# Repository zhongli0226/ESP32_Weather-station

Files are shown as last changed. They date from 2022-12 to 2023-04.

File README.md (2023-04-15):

# ESP32气象站

## 毕设版本V1.0.0

#### 介绍
开源一下我的毕业设计 

基于esp32设计的桌面时钟气象站

#### 架构说明

1. 主程序采用esp32-idf代码 版本为V4.3 芯片为esp32-pico。
2. pc模拟与主工程 LVGL采用V7.9版本 。
3. 硬件由使用AD画的，结构设计采用SOLIDWORKS组装。

#### 使用说明

1.  主工程在spi地方，本人修改了spi源码的一个变量，如直接编译提到代码，运行会出现spi报错，可根据需要进行修改一下。
2.  目前获取天气的网站采用心知天气，用的是本人自己的密钥，可根据需要更换为自己的。
3.  lvgl PC模拟器采用visual studio 2022 需要安装2019（v142）平台工具集，否则无法编译。

#### 未来计划

* [x] 取消SD卡配网方式，采用smartcofig和强制门户认证的方式，综合配网
* [ ] 硬件电路上增加锂电池电源管理部分
* [x] lvgl进一步学习，优化动画效果

## 改进版V2.0.0

#### 架构说明

1. 主程序采用esp32-idf代码 版本为V4.4 芯片为esp32-pico。
2. pc模拟与主工程 LVGL采用V7.10版本 。
3. 硬件延续采用V1.0.0版本，可兼容使用。

#### 改进说明

1. 配网方式采用smartcofig ，且带有存储WiFi信息功能，重新开机自动连接。
2. 优化主界面布局，UI布局优化
3. 取消SD卡输入WiFi信息和地址信息，利用IP定位确定地址。

#### 未来计划

* [ ] 硬件和结构的优化，整体布局优化
* [ ] 触摸按键功能考虑是否加上。

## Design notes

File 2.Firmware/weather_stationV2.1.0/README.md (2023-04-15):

# 桌面气象站升级

#### 介绍
项目来源于稚辉君所做的小电视，后作为我本科毕业设计，现工作后想要继续改进功能所创立。

#### 软件架构
软件架构说明 ESP32-IDF v4.4版本
                         LVGL v7.8.0版本

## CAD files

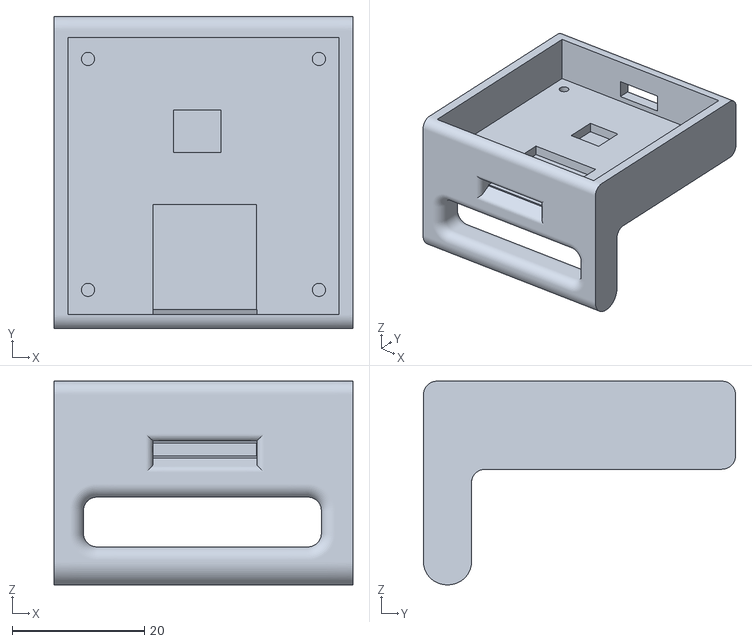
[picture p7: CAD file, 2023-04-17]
3.3D Model/V2.0.0/底座.stl
45.1 x 47.1 x 30.8

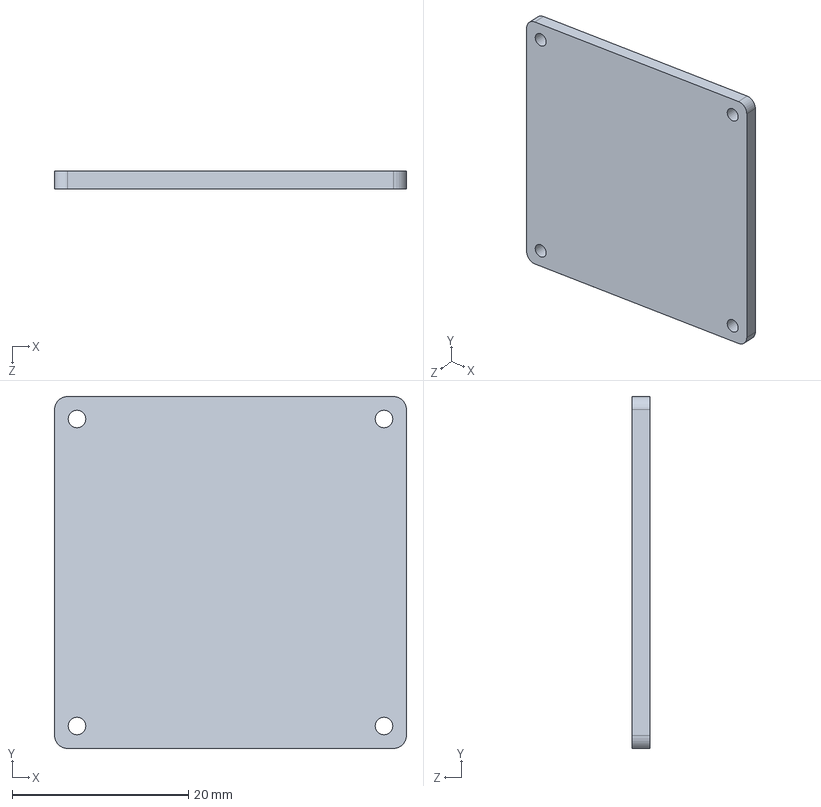
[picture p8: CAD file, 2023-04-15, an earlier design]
3.3D Model/V1.0.0/底板.SLDPRT
40.0 x 40.0 x 2.00 mm

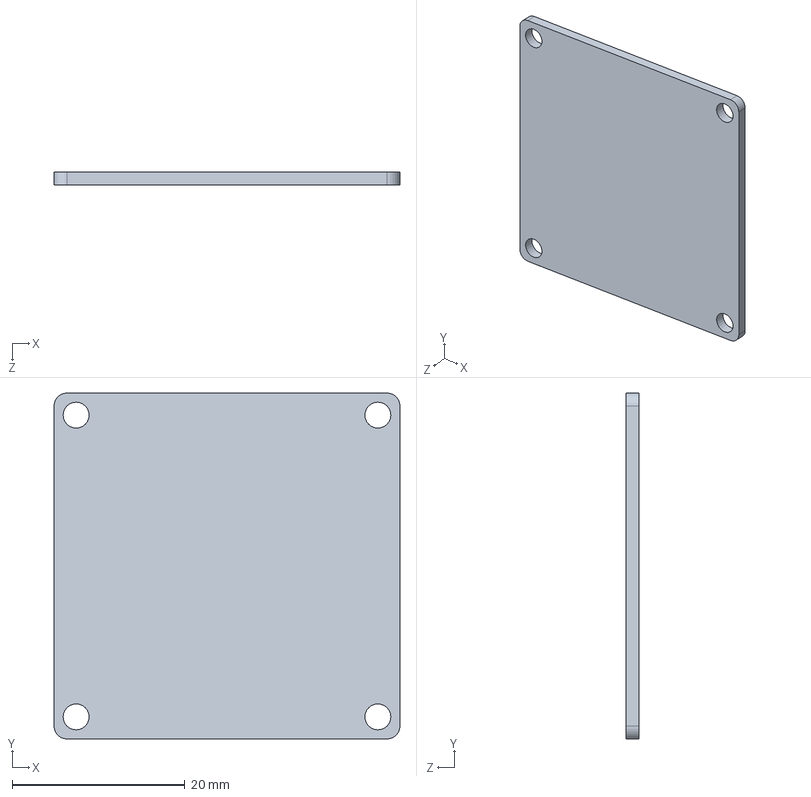
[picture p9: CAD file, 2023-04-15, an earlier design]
3.3D Model/V1.0.0/底板切割.SLDPRT
40.0 x 40.0 x 1.50 mm

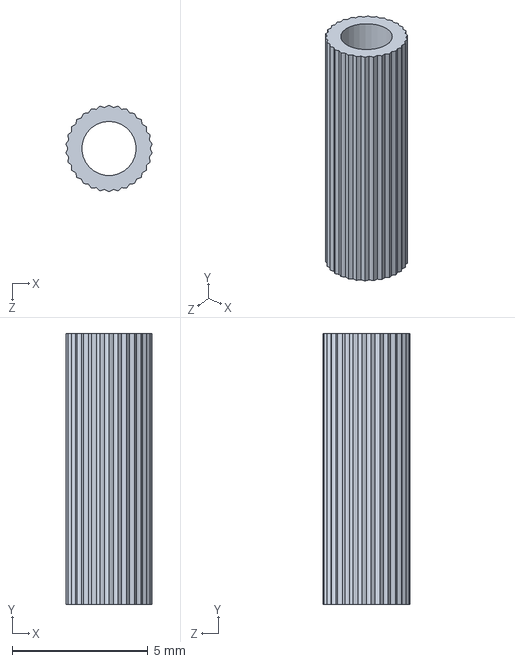
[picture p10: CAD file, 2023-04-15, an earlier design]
3.3D Model/V1.0.0/m2铜柱.SLDPRT
3.18 x 10.0 x 3.20 mm

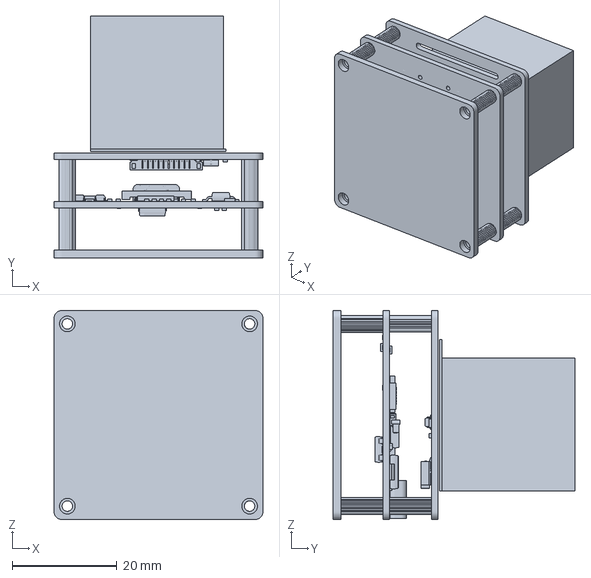
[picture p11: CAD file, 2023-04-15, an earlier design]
3.3D Model/V1.0.0/3d概念图.3MF
40.0 x 46.3 x 40.0 mm

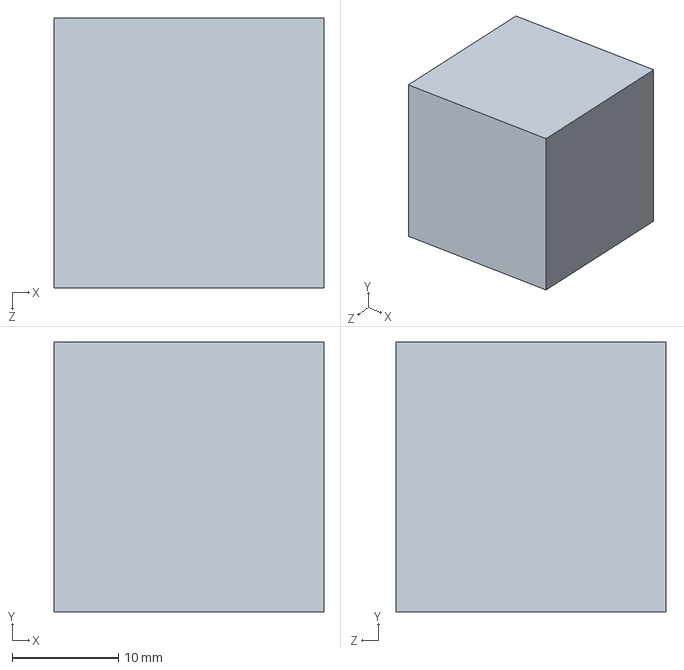
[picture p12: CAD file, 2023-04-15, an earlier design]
3.3D Model/V1.0.0/分光棱镜.SLDPRT
25.4 x 25.4 x 25.4 mm

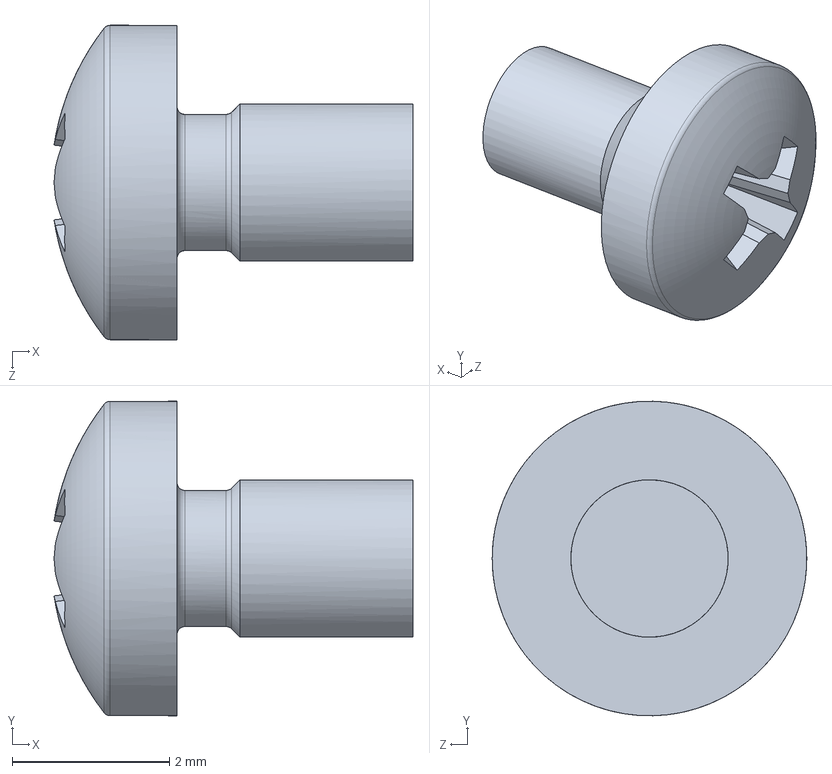
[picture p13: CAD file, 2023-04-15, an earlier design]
3.3D Model/V1.0.0/GB╱T 818-2016[十字槽盘头螺钉M2×3].sldprt
4.56 x 4.00 x 4.00 mm

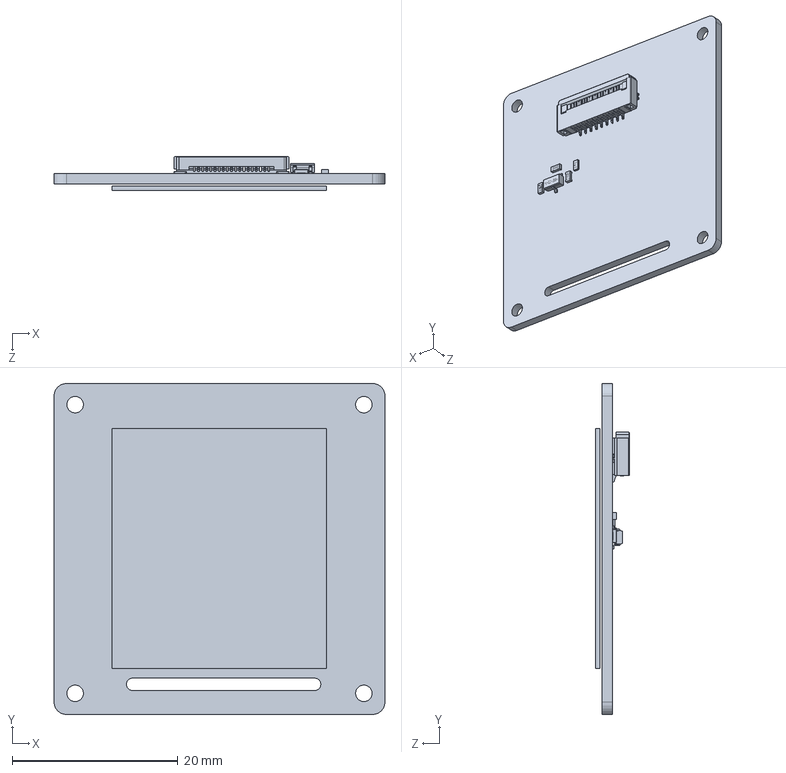
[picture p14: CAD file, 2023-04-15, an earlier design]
3.3D Model/V1.0.0/TFT.SLDPRT
40.0 x 40.0 x 4.05 mm

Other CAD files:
3.3D Model/V1.0.0/屏幕草图.SLDPRT
3.3D Model/V1.0.0/屏幕草图.DWG
3.3D Model/V1.0.0/底板切割.DWG
3.3D Model/V1.0.0/底板切割.DXF

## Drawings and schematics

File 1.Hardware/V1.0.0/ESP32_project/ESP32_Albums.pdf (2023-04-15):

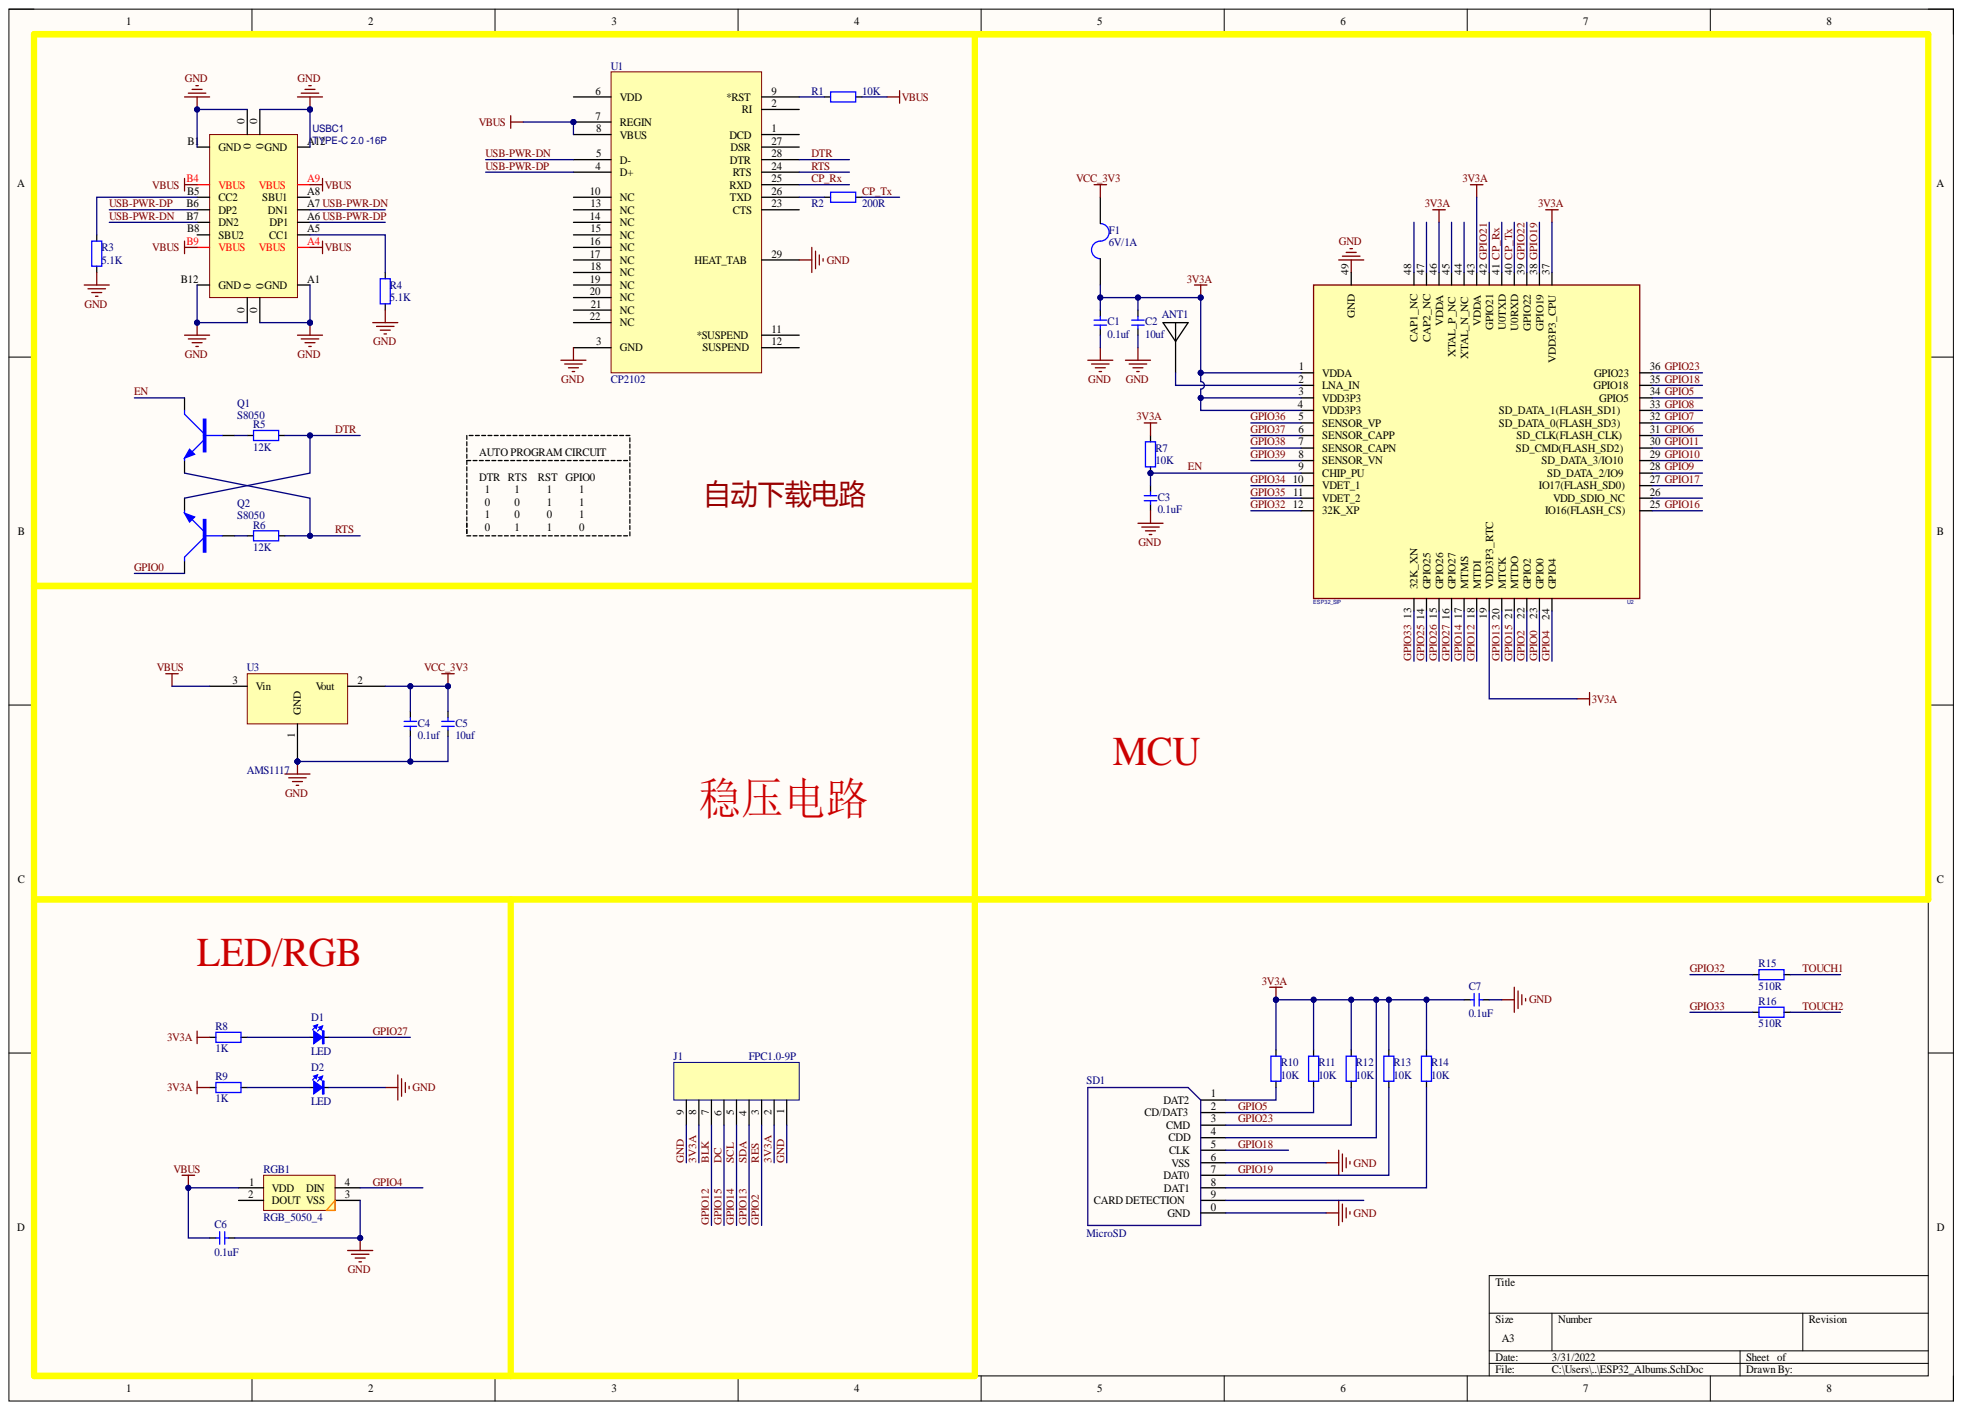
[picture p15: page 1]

GPIO18

GPIO19

Comment | Description | Designator | Footprint | LibRef | Quantity
ANT2 | 贴片天线 | ANT1 | ANT2051 | ANT2 | 1
0.1uf | 无极性电容 | C1, C3, C4, C6, C7 | 0603C | CAP | 5
10uf | 无极性电容 | C2, C5 | 0603C | CAP | 2
LED | | D1, D2 | LED_0603_R | LED | 2
6V/1A | | F1 | FUSE-0805 | FUSE | 1
FPC1.0-9P | 贴片 | J1 | FPC1.0-9P | FPC1.0-9P | 1
S8050 | NPN三极管 | Q1, Q2 | SOT-23 | NPN | 2
10K | | R1, R7, R10, R11, R12, R13, R14 | 0603R | RES | 7
200R | | R2 | 0603R | RES | 1
5.1K | | R3, R4 | 0603R | RES | 2
12K | | R5, R6 | 0603R | RES | 2
1K | | R8, R9 | 0603R | RES | 2
510R | | R15, R16 | 0603R | RES | 2
RGB_5050_4 | | RGB1 | RGB_5050_4 | RGB_5050_4 | 1
MicroSD | | SD1 | Micro SD | MicroSD | 1
CP2102 | USB转TTL | U1 | LC-QFN-28_5x5x05P | CP2102 | 1
ESP32_SIP | | U2 | QFN-48_7X7 | ESP32-PICO | 1
AMS1117 | 三端稳压芯片 | U3 | SOT223 | AMS1117 | 1
TYPE-C 2.0 -16P | USB2.0 Type-C 16Pin 母座 | USBC1 | USB-C-SMD_16P | USB2.0_Type-C_16Pin | 1

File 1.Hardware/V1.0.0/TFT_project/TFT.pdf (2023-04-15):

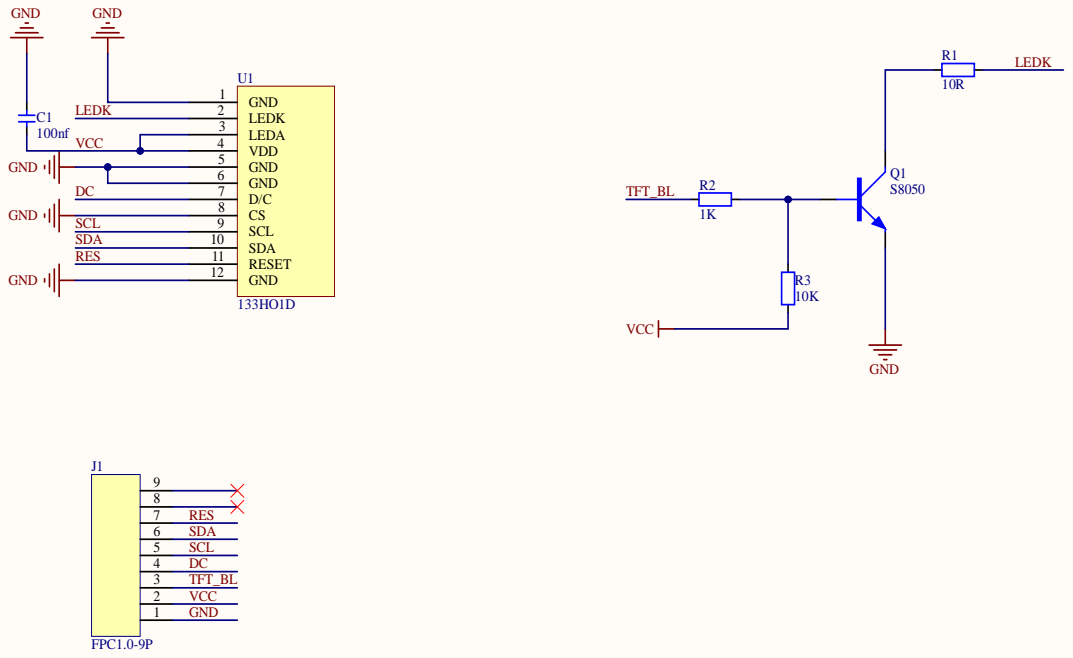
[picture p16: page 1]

Comment | Description | Designator | Footprint | LibRef | Quantity
100nf | 无极性电容 | C1 | 0603C | CAP | 1
FPC1.0-9P | 贴片 | J1 | FPC1.0-9P | FPC1.0-9P | 1
S8050 | NPN三极管 | Q1 | SOT-23 | NPN | 1
10R | | R1 | 0603R | RES | 1
1K | | R2 | 0603R | RES | 1
10K | | R3 | 0603R | RES | 1
133HO1D | 1.3 TFT IPS | U1 | LCD-240X240-NOHOLE | 133HO1D | 1

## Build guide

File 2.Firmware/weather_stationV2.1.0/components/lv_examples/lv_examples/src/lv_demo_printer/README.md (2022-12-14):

# Printer demo

## Overview
A printer example created with LVGL. This demo is optmized for 800x480 resolution and among many others it demonstrates custom theme creation, style transitions and animations. 

The demo uses some images with 32 bit color depth they require ~1.6 MB flash. With 16 bit color depth ~900KB is required for the images.

Printer demo with LVGL embedded GUI library

## Run the demo
- In `lv_ex_conf.h` set `LV_USE_DEMO_PRINTER 1`
- After `lv_init()` and initializing the drivers call `lv_demo_printer()`

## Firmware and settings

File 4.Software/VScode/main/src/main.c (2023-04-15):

/**
 * @file main
 *
 */

 /*********************
  *      INCLUDES
  *********************/
#define _DEFAULT_SOURCE /* needed for usleep() */
#include <stdlib.h>
#include <unistd.h>
#include <stdio.h>
#include <string.h>
#include <time.h>
#define SDL_MAIN_HANDLED /*To fix SDL's "undefined reference to WinMain" \
                            issue*/
#include "SDL2/SDL.h"
#include "lvgl/lvgl.h"
#include "lv_drivers/display/monitor.h"
#include "lv_drivers/indev/mouse.h"
#include "lv_drivers/indev/keyboard.h"
#include "lv_drivers/indev/mousewheel.h"
#include "lv_examples/lv_examples.h"
  /*********************
   *      DEFINES
   *********************/
LV_IMG_DECLARE(Sunny);
#define WEATHER_1  "\xEE\x98\x85"  //11
#define WEATHER_2  "\xEE\x98\x86"  //15
#define WEATHER_3  "\xEE\x98\x87"  //17
#define WEATHER_4  "\xEE\x98\x88"  //16
#define WEATHER_5  "\xEE\x98\x89"  //12
#define WEATHER_6  "\xEE\x98\x8A"  //0 2 38
#define WEATHER_7  "\xEE\x98\x8B"  //13
#define WEATHER_8  "\xEE\x98\x8C"  //18
#define WEATHER_9  "\xEE\x98\x8D"  //6 8
#define WEATHER_10  "\xEE\x98\x8E"  //1 3
#define WEATHER_11  "\xEE\x98\x8F"  //9
#define WEATHER_12  "\xEE\x98\x90"  //14
#define WEATHER_13  "\xEE\x98\x91"  //20
#define WEATHER_14  "\xEE\x98\x92"  //10
#define WEATHER_15  "\xEE\x98\x93"  //4 5 7
#define WEATHER_16  "\xEE\x98\x94"  //25 37
#define WEATHER_17  "\xEE\x98\x95"  //24
#define WEATHER_18  "\xEE\x98\x96"  //19
#define WEATHER_19  "\xEE\x98\x97"  //28
#define WEATHER_20  "\xEE\x98\x98"  //26
#define WEATHER_21  "\xEE\x98\x99"  //30
#define WEATHER_22  "\xEE\x98\x9A"  //29
#define WEATHER_23  "\xEE\x98\x9B"  //22
#define WEATHER_24  "\xEE\x98\x9C"  //31
#define WEATHER_25  "\xEE\x98\x9D"  //27
#define WEATHER_26  "\xEE\x98\x9E"  //23
#define WEATHER_27  "\xEE\x98\x9F"  //32 33 34 35 36 
#define WEATHER_28  "\xEE\x98\xA0"  //21
#define WEATHER_29  "\xEE\x99\xB6"  //99

#define HUMIDITU  "\xEE\x9C\x9D"
#define WIND_MESS "\xEE\x9A\x96"
/**********************
*      TYPEDEFS
**********************/
typedef struct _lv_clock
{
  lv_obj_t* time_label; // 时间标签
  lv_obj_t* data_label; // 日期标签
  lv_obj_t* weekday_label; //星期标签
  lv_obj_t* temperature_daily_label;//当日天气范围
  lv_obj_t* temperature_now_label;//实时温度
  lv_obj_t* weather_code_label;//天气代码
  lv_obj_t* ip_label;//地点标签
  lv_obj_t* humi_label;//湿度
  lv_obj_t* wind_label;//风力
}lv_clock_t;
/**********************
 *  STATIC PROTOTYPES
 **********************/
static void hal_init(void);
static int tick_thread(void* data);
static void memory_monitor(lv_task_t* param);

/**********************
 *  STATIC VARIABLES
 **********************/
lv_disp_buf_t disp_buf1;
lv_color_t buf1_1[LV_HOR_RES_MAX * 120];
lv_disp_drv_t disp_drv;
lv_indev_drv_t mouse_drv;
lv_indev_drv_t keyb_drv;
lv_indev_drv_t enc_drv;


static int flag_wifi = 0;
static int flag_history = 0;
static int flag_connect_succ = 0;

/**********************
 *      MACROS
 **********************/
 // bar任务
static void bar_anim(lv_task_t* t)
{
  static uint32_t x = 0;				// 静态变量Bar可变值
  static uint32_t state = 0;
  static char buf[64];
  lv_obj_t* bar = t->user_data;		// 从任务参数中获取bar对象
  lv_bar_set_value(bar, x, LV_ANIM_OFF);				// 设置值，关闭动画
  switch (state)
  {
  case 0:
    if (!flag_history)
    {
      if (x < 20)
      {
        x++;
      }
      lv_snprintf(buf, sizeof(buf), "Find historical data!");
      lv_obj_set_style_local_value_str(bar, LV_BAR_PART_BG, LV_STATE_DEFAULT, buf);// 显示字符串
      //printf("查找历史数据\n");
    }
    else           //到来事件状态改变，进度条设置为20
    {
      state = 1;
      x = 20;
    }
    break;
  case 1:
    if (!flag_wifi)
    {
      if (x < 50)
      {
        x++;
      }
      lv_snprintf(buf, sizeof(buf), "WiFi Connect!");
      lv_obj_set_style_local_value_str(bar, LV_BAR_PART_BG, LV_STATE_DEFAULT, buf);// 显示字符串
      //printf("wifi 连接\n");
    }
    else            //到来事件状态改变，进度条设置为50
    {
      state = 2;
      x = 50;
    }
    break;
  case 2:
    if (!flag_connect_succ)
    {
      if (x < 100)
      {
        x++;
      }
      lv_snprintf(buf, sizeof(buf), "Wait for connect! ");
      lv_obj_set_style_local_value_str(bar, LV_BAR_PART_BG, LV_STATE_DEFAULT, buf);// 显示字符串
      //printf("等待连接成功\n");
    }
    else            //到来事件状态改变，进度条设置为100
    {
      state = 3;
      x = 100;
      lv_snprintf(buf, sizeof(buf), "Connect success! ");
      lv_obj_set_style_local_value_str(bar, LV_BAR_PART_BG, LV_STATE_DEFAULT, buf);// 显示字符串
    }
    break;

  default:
    break;
  }
}
static void Events_Simulation(lv_task_t* t)
{
  static uint32_t time = 0;
  time++;
  if (time == 4)
  {
    flag_history = 1;
  }
  if (time == 7)
  {
    flag_wifi = 1;
  }
  if (time == 9)
  {
    flag_connect_succ = 1;
  }
  if (time >= 10)
  {
    time = 10;
  }
}
void bar_demo(void)
{
  lv_obj_t* bar = lv_bar_create(lv_scr_act(), NULL);
  lv_bar_set_type(bar, LV_BAR_TYPE_NORMAL);
  lv_obj_set_size(bar, 200, 20);                    // 控件尺寸
  lv_obj_align(bar, NULL, LV_ALIGN_CENTER, 0, 0);   // 对齐到中心
  lv_bar_set_range(bar, 0, 100);                    // 设置范围，最小值，最大值
  // 设置本地属性->字体
  lv_obj_set_style_local_value_font(bar, LV_BAR_PART_BG, LV_STATE_DEFAULT, &lv_font_montserrat_16);
  // 设置本地属性->对齐
  lv_obj_set_style_local_value_align(bar, LV_BAR_PART_BG, LV_STATE_DEFAULT, LV_ALIGN_OUT_BOTTOM_MID);
  // 设置本地属性->Y轴偏移
  lv_obj_set_style_local_value_ofs_y(bar, LV_BAR_PART_BG, LV_STATE_DEFAULT, LV_DPI / 20);
  // 设置本地属性->底部边距
  lv_obj_set_style_local_margin_bottom(bar, LV_BAR_PART_BG, LV_STATE_DEFAULT, LV_DPI / 7);
  // 设置字体颜色
  lv_obj_set_style_local_value_color(bar, LV_BAR_PART_BG, LV_STATE_DEFAULT, lv_color_hex(0x2196f3));
  //设置进度条背景颜色
  lv_obj_set_style_local_bg_color(bar, LV_BAR_PART_BG, LV_STATE_DEFAULT, lv_color_hex(0xf5f5f5));
  // 设置进度条颜色
  lv_obj_set_style_local_bg_color(bar, LV_BAR_PART_INDIC, LV_STATE_DEFAULT, lv_color_hex(0x2196f3));
  // 设置进度条边框颜色和大小
  lv_obj_set_style_local_border_color(bar, LV_BAR_PART_BG, LV_STATE_DEFAULT, lv_color_hex(0x2196f3));
  lv_obj_set_style_local_border_width(bar, LV_BAR_PART_BG, LV_STATE_DEFAULT, 2);
  lv_obj_set_style_local_pad_all(bar, LV_BAR_PART_BG, LV_STATE_DEFAULT, 6);
  lv_obj_set_style_local_radius(bar, LV_BAR_PART_BG, LV_STATE_DEFAULT, 6);

  lv_bar_set_start_value(bar, 0, LV_ANIM_OFF);      // 设置开始值，非动画方式
  lv_task_create(bar_anim, 50, LV_TASK_PRIO_LOWEST, bar);
  lv_task_create(Events_Simulation, 700, LV_TASK_PRIO_LOWEST, NULL);
}
static void clock_date_task_callback(lv_task_t* task)
{
  static const char* week_day[7] = { "Sunday","Monday","Tuesday","Wednesday","Thursday","Friday","Saturday" };
  static time_t unix_time;
  static struct tm* time_info;
  unix_time = time(NULL);
  time_info = localtime(&unix_time);

  int year = time_info->tm_year + 1900;
  int month = time_info->tm_mon + 1;
  int day = time_info->tm_mday;
  int weekday = time_info->tm_wday;
  int hour = time_info->tm_hour;
  int minutes = time_info->tm_min;
  int second = time_info->tm_sec;

  lv_clock_t* clock = (lv_clock_t*)(task->user_data);

  lv_label_set_text_fmt(clock->time_label, "%02d:%02d:%02d", hour, minutes, second);
  lv_obj_align(clock->time_label, lv_obj_get_parent(clock->time_label), LV_ALIGN_CENTER, 0, -10);

  lv_label_set_text_fmt(clock->data_label, "%d-%02d-%02d", year, month, day);
  lv_obj_align(clock->data_label, lv_obj_get_parent(clock->data_label), LV_ALIGN_IN_BOTTOM_LEFT, 5, -5);

  lv_label_set_text_fmt(clock->weekday_label, "%s", week_day[weekday]);
  lv_obj_align(clock->weekday_label, lv_obj_get_parent(clock->weekday_label), LV_ALIGN_IN_BOTTOM_RIGHT, -5, -5);
}
void lv_main_ui(void)
{
  int temperature = 30;
  char* ip = "shenzhen";
  char* humi = "70";
  char* wind = "2";
  static lv_style_t style_bg;
  lv_style_init(&style_bg);
  lv_style_set_bg_color(&style_bg, LV_STATE_DEFAULT, lv_color_hex(0x41485a));
  lv_obj_add_style(lv_scr_act(), LV_OBJ_PART_MAIN, &style_bg);

  static lv_clock_t lv_clock = { 0 };
  ///////////////////////////////////////中间时钟部分设计
  static lv_style_t style_clock;
  lv_style_reset(&style_clock);
  lv_style_init(&style_clock);
  lv_style_set_bg_color(&style_clock, LV_STATE_DEFAULT, lv_color_hex(0x41485a));
  lv_style_set_border_color(&style_clock, LV_STATE_DEFAULT, lv_color_hex(0x41485a));

  static lv_style_t style_lab_time;
  lv_style_reset(&style_lab_time);
  lv_style_init(&style_lab_time);
  lv_style_set_text_color(&style_lab_time, LV_STATE_DEFAULT, LV_COLOR_ORANGE); //字体颜色
  lv_style_set_text_font(&style_lab_time, LV_STATE_DEFAULT, &lv_font_montserrat_48);//字体大小

  static lv_style_t style_lab_data_weekday;
  lv_style_reset(&style_lab_data_weekday);
  lv_style_init(&style_lab_data_weekday);
  lv_style_set_text_color(&style_lab_data_weekday, LV_STATE_DEFAULT, LV_COLOR_WHITE); //字体颜色
  lv_style_set_text_font(&style_lab_data_weekday, LV_STATE_DEFAULT, &lv_font_montserrat_18);//字体大小

  lv_obj_t* obj_mid = lv_obj_create(lv_scr_act(), NULL);
  lv_obj_set_size(obj_mid, 210, 80); // 设置对象大小
  lv_obj_align(obj_mid, lv_scr_act(), LV_ALIGN_CENTER, 0, 0);
  lv_obj_add_style(obj_mid, LV_OBJ_PART_MAIN, &style_clock);

  lv_clock.time_label = lv_label_create(obj_mid, NULL);//创建文本
  lv_obj_add_style(lv_clock.time_label, LV_LABEL_PART_MAIN, &style_lab_time);

  lv_clock.data_label = lv_label_create(obj_mid, NULL);
  lv_obj_add_style(lv_clock.data_label, LV_LABEL_PART_MAIN, &style_lab_data_weekday);

  lv_clock.weekday_label = lv_label_create(obj_mid, NULL);
  lv_obj_add_style(lv_clock.weekday_label, LV_LABEL_PART_MAIN, &style_lab_data_weekday);
  ////////////////////////////顶部天气部分设计
  static lv_style_t style_weather;
  lv_style_reset(&style_weather);
  lv_style_init(&style_weather);
  lv_style_set_bg_color(&style_weather, LV_STATE_DEFAULT, lv_color_hex(0x41485a));
  lv_style_set_border_color(&style_weather, LV_STATE_DEFAULT, lv_color_hex(0x41485a));

  lv_obj_t* obj_top = lv_obj_create(lv_scr_act(), NULL);
  lv_obj_set_size(obj_top, 240, 80); // 设置对象大小
  lv_obj_align(obj_top, lv_scr_act(), LV_ALIGN_IN_TOP_MID, 0, 0);
  lv_obj_add_style(obj_top, LV_OBJ_PART_MAIN, &style_weather);

  static lv_style_t style_weather_text;											// 创建一个风格
  lv_style_init(&style_weather_text);// 初始化风格
  lv_style_set_text_color(&style_weather_text, LV_STATE_DEFAULT, lv_color_hex(0xff00fa)); //字体颜色
  lv_style_set_text_font(&style_weather_text, LV_STATE_DEFAULT, &lv_font_montserrat_48);

  static lv_style_t style_weather_text2;											// 创建一个风格
  lv_style_init(&style_weather_text2);// 初始化风格
  lv_style_set_text_color(&style_weather_text2, LV_STATE_DEFAULT, lv_color_hex(0xff00fa)); //字体颜色
  lv_style_set_text_font(&style_weather_text2, LV_STATE_DEFAULT, &lv_font_montserrat_18);

  static lv_style_t weather_code_style;
  lv_style_init(&weather_code_style);
  lv_style_set_text_color(&weather_code_style, LV_STATE_DEFAULT, lv_color_hex(0x79b8ff)); //字体颜色
  lv_style_set_text_font(&weather_code_style, LV_STATE_DEFAULT, &my_font_70);

  lv_clock.weather_code_label = lv_label_create(obj_top, NULL);
  lv_obj_add_style(lv_clock.weather_code_label, LV_LABEL_PART_MAIN, &weather_code_style);		// 应用效果风格
  lv_label_set_text(lv_clock.weather_code_label, WEATHER_22);// 设置显示文本
  lv_obj_align(lv_clock.weather_code_label, obj_top, LV_ALIGN_IN_TOP_LEFT, 20, 5); // 重新设置对齐

  lv_clock.temperature_now_label = lv_label_create(obj_top, NULL);
  lv_obj_add_style(lv_clock.temperature_now_label, LV_LABEL_PART_MAIN, &style_weather_text);		// 应用效果风格
  lv_label_set_text_fmt(lv_clock.temperature_now_label, "%d°", temperature);
  lv_obj_align(lv_clock.temperature_now_label, obj_top, LV_ALIGN_IN_TOP_MID, 55, 0);

  lv_clock.temperature_daily_label = lv_label_create(obj_top, NULL);
  lv_obj_add_style(lv_clock.temperature_daily_label, LV_LABEL_PART_MAIN, &style_weather_text2);		// 应用效果风格
  lv_label_set_text_fmt(lv_clock.temperature_daily_label, LV_SYMBOL_UP " %d°    " LV_SYMBOL_DOWN " %d°", temperature, temperature);
  lv_obj_align(lv_clock.temperature_daily_label, obj_top, LV_ALIGN_IN_BOTTOM_RIGHT, -15, -5);
  ////////////////////////////////////底部天气地点设定
  lv_obj_t* obj_bottom = lv_obj_create(lv_scr_act(), NULL);
  lv_obj_set_size(obj_bottom, 240, 80); // 设置对象大小
  lv_obj_align(obj_bottom, lv_scr_act(), LV_ALIGN_IN_BOTTOM_MID, 0, 0);
  lv_obj_add_style(obj_bottom, LV_OBJ_PART_MAIN, &style_weather);

  lv_clock.ip_label = lv_label_create(obj_bottom, NULL);
  lv_obj_add_style(lv_clock.ip_label, LV_LABEL_PART_MAIN, &style_weather_text2);		// 应用效果风格
  lv_label_set_text_fmt(lv_clock.ip_label, LV_SYMBOL_GPS " %s", ip);
  lv_obj_align(lv_clock.ip_label, obj_bottom, LV_ALIGN_IN_BOTTOM_LEFT, 0, 0);

  static lv_style_t icon_style;
  lv_style_init(&icon_style);
  lv_style_set_text_color(&icon_style, LV_STATE_DEFAULT, lv_color_hex(0x79b8ff)); //字体颜色
  lv_style_set_text_font(&icon_style, LV_STATE_DEFAULT, &my_font_30);

  static lv_style_t humi_style;
  lv_style_init(&humi_style);
  lv_style_set_text_color(&humi_style, LV_STATE_DEFAULT, lv_color_hex(0x79b8ff)); //字体颜色
  lv_style_set_text_font(&humi_style, LV_STATE_DEFAULT, &lv_font_montserrat_32);

  lv_obj_t* humi_icon_label = lv_label_create(obj_bottom, NULL);
  lv_obj_add_style(humi_icon_label, LV_LABEL_PART_MAIN, &icon_style);		// 应用效果风格
  lv_label_set_text_fmt(humi_icon_label, HUMIDITU);
  lv_obj_align(humi_icon_label, obj_bottom, LV_ALIGN_IN_TOP_LEFT, 5, 10);

  lv_clock.humi_label = lv_label_create(obj_bottom, NULL);
  lv_obj_add_style(lv_clock.humi_label, LV_LABEL_PART_MAIN, &humi_style);		// 应用效果风格
  lv_label_set_text_fmt(lv_clock.humi_label, "%s", humi);
  lv_obj_align(lv_clock.humi_label, obj_bottom, LV_ALIGN_IN_TOP_LEFT, 40, 5);

  lv_obj_t* wind_icon_label = lv_label_create(obj_bottom, NULL);
  lv_obj_add_style(wind_icon_label, LV_LABEL_PART_MAIN, &icon_style);		// 应用效果风格
  lv_label_set_text_fmt(wind_icon_label, WIND_MESS);
  lv_obj_align(wind_icon_label, obj_bottom, LV_ALIGN_IN_TOP_MID, 35, 10);

  lv_clock.wind_label = lv_label_create(obj_bottom, NULL);
  lv_obj_add_style(lv_clock.wind_label, LV_LABEL_PART_MAIN, &humi_style);		// 应用效果风格
  lv_label_set_text_fmt(lv_clock.wind_label, "%s", wind);
  lv_obj_align(lv_clock.wind_label, obj_bottom, LV_ALIGN_IN_TOP_MID, 70, 5);

  lv_task_t* task_timer = lv_task_create(clock_date_task_callback, 200, LV_TASK_PRIO_MID, &lv_clock);  // 创建定时任务，200ms刷新一次
  lv_task_ready(task_timer);
}
/**********************
 *   GLOBAL FUNCTIONS
 **********************/

int main(int argc, char** argv)
{
  (void)argc; /*Unused*/
  (void)argv; /*Unused*/

  /*Initialize LVGL*/
  lv_init();

  /*Initialize the HAL (display, input devices, tick) for LVGL*/
  hal_init();

  //  lv_demo_widgets();
    /* For printer demo set resolution to 800x480 */
  //  lv_demo_printer();
  //  lv_demo_keypad_encoder();
  //  lv_demo_benchmark();
  //  lv_demo_stress();
  //  lv_demo_music();
  //bar_demo();
  lv_main_ui();
  while (1) {
    /* Periodically call the lv_task handler.
     * It could be done in a timer interrupt or an OS task too.*/
    lv_task_handler();
    usleep(5 * 1000);
  }

  return 0;
}

/**********************
 *   STATIC FUNCTIONS
 **********************/

 /**
  * Initialize the Hardware Abstraction Layer (HAL) for the Littlev graphics
  * library
  */
static void hal_init(void) {
  /* Use the 'monitor' driver which creates window on PC's monitor to simulate a display*/
  monitor_init();

  /*Create a display buffer*/
  lv_disp_buf_init(&disp_buf1, buf1_1, NULL, LV_HOR_RES_MAX * 120);

  /*Create a display*/
  lv_disp_drv_init(&disp_drv); /*Basic initialization*/
  disp_drv.buffer = &disp_buf1;
  disp_drv.flush_cb = monitor_flush;
  lv_disp_drv_register(&disp_drv);

  /* Add the mouse as input device
   * Use the 'mouse' driver which reads the PC's mouse*/
  mouse_init();
  lv_indev_drv_init(&mouse_drv); /*Basic initialization*/
  mouse_drv.type = LV_INDEV_TYPE_POINTER;

  /*This function will be called periodically (by the library) to get the mouse position and state*/
  mouse_drv.read_cb = mouse_read;
  lv_indev_t* mouse_indev = lv_indev_drv_register(&mouse_drv);

  /*Set a cursor for the mouse*/
  LV_IMG_DECLARE(mouse_cursor_icon); /*Declare the image file.*/
  lv_obj_t* cursor_obj = lv_img_create(lv_scr_act(), NULL); /*Create an image object for the cursor */
  lv_img_set_src(cursor_obj, &mouse_cursor_icon);           /*Set the image source*/
  lv_indev_set_cursor(mouse_indev, cursor_obj);             /*Connect the image  object to the driver*/

  /* Add the keyboard as input device
   * Use the 'keyboard' driver which reads the PC's keyboard*/
  keyboard_init();
  lv_indev_drv_init(&keyb_drv);
  keyb_drv.type = LV_INDEV_TYPE_KEYPAD;
  keyb_drv.read_cb = keyboard_read;
  lv_indev_drv_register(&keyb_drv);

  /* Add the mouse wheel as input device (encoder type)
   * Use the 'mousewheel' driver which reads the PC's mouse wheel*/
  mousewheel_init();
  lv_indev_drv_init(&enc_drv);
  enc_drv.type = LV_INDEV_TYPE_ENCODER;
  enc_drv.read_cb = mousewheel_read;
  lv_indev_drv_register(&enc_drv);

  /* Tick init.
   * You have to call 'lv_tick_inc()' in periodically to inform LittelvGL about
   * how much time were elapsed Create an SDL thread to do this*/
  SDL_CreateThread(tick_thread, "tick", NULL);

  /* Optional:
   * Create a memory monitor task which prints the memory usage in
   * periodically.*/
  lv_task_create(memory_monitor, 5000, LV_TASK_PRIO_MID, NULL);
}

/**
 * A task to measure the elapsed time for LVGL
 * @param data unused
 * @return never return
 */
static int tick_thread(void* data) {
  (void)data;

  while (1) {
    SDL_Delay(5);   /*Sleep for 5 millisecond*/
    lv_tick_inc(5); /*Tell LittelvGL that 5 milliseconds were elapsed*/
  }

  return 0;
}

/**
 * Print the memory usage periodically
 * @param param
 */
static void memory_monitor(lv_task_t* param) {
  (void)param; /*Unused*/

  lv_mem_monitor_t mon;
  lv_mem_monitor(&mon);
  printf("used: %6d (%3d %%), frag: %3d %%, biggest free: %6d\n",
    (int)mon.total_size - mon.free_size, mon.used_pct, mon.frag_pct,
    (int)mon.free_biggest_size);
}

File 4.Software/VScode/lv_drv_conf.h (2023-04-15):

/**
 * @file lv_drv_conf.h
 * Configuration file for v7.11.0
 */

/*
 * COPY THIS FILE AS lv_drv_conf.h
 */

#if 1 /*Set it to "1" to enable the content*/

#ifndef LV_DRV_CONF_H
#define LV_DRV_CONF_H

#include "lv_conf.h"

/*********************
 * DELAY INTERFACE
 *********************/
#define LV_DRV_DELAY_INCLUDE  <stdint.h>            /*Dummy include by default*/
#define LV_DRV_DELAY_US(us)  /*delay_us(us)*/       /*Delay the given number of microseconds*/
#define LV_DRV_DELAY_MS(ms)  /*delay_ms(ms)*/       /*Delay the given number of milliseconds*/

/*********************
 * DISPLAY INTERFACE
 *********************/

/*------------
 *  Common
 *------------*/
#define LV_DRV_DISP_INCLUDE         <stdint.h>           /*Dummy include by default*/
#define LV_DRV_DISP_CMD_DATA(val)  /*pin_x_set(val)*/    /*Set the command/data pin to 'val'*/
#define LV_DRV_DISP_RST(val)       /*pin_x_set(val)*/    /*Set the reset pin to 'val'*/

/*---------
 *  SPI
 *---------*/
#define LV_DRV_DISP_SPI_CS(val)          /*spi_cs_set(val)*/     /*Set the SPI's Chip select to 'val'*/
#define LV_DRV_DISP_SPI_WR_BYTE(data)    /*spi_wr(data)*/        /*Write a byte the SPI bus*/
#define LV_DRV_DISP_SPI_WR_ARRAY(adr, n) /*spi_wr_mem(adr, n)*/  /*Write 'n' bytes to SPI bus from 'adr'*/

/*------------------
 *  Parallel port
 *-----------------*/
#define LV_DRV_DISP_PAR_CS(val)          /*par_cs_set(val)*/   /*Set the Parallel port's Chip select to 'val'*/
#define LV_DRV_DISP_PAR_SLOW             /*par_slow()*/        /*Set low speed on the parallel port*/
#define LV_DRV_DISP_PAR_FAST             /*par_fast()*/        /*Set high speed on the parallel port*/
#define LV_DRV_DISP_PAR_WR_WORD(data)    /*par_wr(data)*/      /*Write a word to the parallel port*/
#define LV_DRV_DISP_PAR_WR_ARRAY(adr, n) /*par_wr_mem(adr,n)*/ /*Write 'n' bytes to Parallel ports from 'adr'*/

/***************************
 * INPUT DEVICE INTERFACE
 ***************************/

/*----------
 *  Common
 *----------*/
#define LV_DRV_INDEV_INCLUDE     <stdint.h>             /*Dummy include by default*/
#define LV_DRV_INDEV_RST(val)    /*pin_x_set(val)*/     /*Set the reset pin to 'val'*/
#define LV_DRV_INDEV_IRQ_READ    0 /*pn_x_read()*/      /*Read the IRQ pin*/

/*---------
 *  SPI
 *---------*/
#define LV_DRV_INDEV_SPI_CS(val)            /*spi_cs_set(val)*/     /*Set the SPI's Chip select to 'val'*/
#define LV_DRV_INDEV_SPI_XCHG_BYTE(data)    0 /*spi_xchg(val)*/     /*Write 'val' to SPI and give the read value*/

/*---------
 *  I2C
 *---------*/
#define LV_DRV_INDEV_I2C_START              /*i2c_start()*/       /*Make an I2C start*/
#define LV_DRV_INDEV_I2C_STOP               /*i2c_stop()*/        /*Make an I2C stop*/
#define LV_DRV_INDEV_I2C_RESTART            /*i2c_restart()*/     /*Make an I2C restart*/
#define LV_DRV_INDEV_I2C_WR(data)           /*i2c_wr(data)*/      /*Write a byte to the I1C bus*/
#define LV_DRV_INDEV_I2C_READ(last_read)    0 /*i2c_rd()*/        /*Read a byte from the I2C bud*/


/*********************
 *  DISPLAY DRIVERS
 *********************/

/*-------------------
 *  Monitor of PC
 *-------------------*/
#ifndef USE_MONITOR
#  define USE_MONITOR         1
#endif

#if USE_MONITOR
#  define MONITOR_HOR_RES     LV_HOR_RES_MAX
#  define MONITOR_VER_RES     LV_VER_RES_MAX

/* Scale window by this factor (useful when simulating small screens) */
#  define MONITOR_ZOOM        1

/* Used to test true double buffering with only address changing.
 * Set LV_VDB_SIZE = (LV_HOR_RES * LV_VER_RES) and  LV_VDB_DOUBLE = 1 and LV_COLOR_DEPTH = 32" */
#  define MONITOR_DOUBLE_BUFFERED 0

/*Eclipse: <SDL2/SDL.h>    Visual Studio: <SDL.h>*/
#  define MONITOR_SDL_INCLUDE_PATH    <SDL2/SDL.h>

/*Open two windows to test multi display support*/
#  define MONITOR_DUAL            0
#endif

/*-----------------------------------
 *  Native Windows (including mouse)
 *----------------------------------*/
#ifndef USE_WINDOWS
#  define USE_WINDOWS       0
#endif

#if USE_WINDOWS
#  define WINDOW_HOR_RES      480
#  define WINDOW_VER_RES      320
#endif

/*----------------------------
 *  Native Windows (win32drv)
 *---------------------------*/
#ifndef USE_WIN32DRV
#  define USE_WIN32DRV       0
#endif

/*----------------------------------------
 *  GTK drivers (monitor, mouse, keyboard
 *---------------------------------------*/
#ifndef USE_GTK
#  define USE_GTK       0
#endif

/*----------------
 *    SSD1963
 *--------------*/
#ifndef USE_SSD1963
#  define USE_SSD1963         0
#endif

#if USE_SSD1963
#  define SSD1963_HOR_RES     LV_HOR_RES
#  define SSD1963_VER_RES     LV_VER_RES
#  define SSD1963_HT          531
#  define SSD1963_HPS         43
#  define SSD1963_LPS         8
#  define SSD1963_HPW         10
#  define SSD1963_VT          288
#  define SSD1963_VPS         12
#  define SSD1963_FPS         4
#  define SSD1963_VPW         10
#  define SSD1963_HS_NEG      0   /*Negative hsync*/
#  define SSD1963_VS_NEG      0   /*Negative vsync*/
#  define SSD1963_ORI         0   /*0, 90, 180, 270*/
#  define SSD1963_COLOR_DEPTH 16
#endif

/*----------------
 *    R61581
 *--------------*/
#ifndef USE_R61581
#  define USE_R61581          0
#endif

#if USE_R61581
#  define R61581_HOR_RES      LV_HOR_RES
#  define R61581_VER_RES      LV_VER_RES
#  define R61581_HSPL         0       /*HSYNC signal polarity*/
#  define R61581_HSL          10      /*HSYNC length (Not Implemented)*/
#  define R61581_HFP          10      /*Horitontal Front poarch (Not Implemented)*/
#  define R61581_HBP          10      /*Horitontal Back poarch (Not Implemented */
#  define R61581_VSPL         0       /*VSYNC signal polarity*/
#  define R61581_VSL          10      /*VSYNC length (Not Implemented)*/
#  define R61581_VFP          8       /*Vertical Front poarch*/
#  define R61581_VBP          8       /*Vertical Back poarch */
#  define R61581_DPL          0       /*DCLK signal polarity*/
#  define R61581_EPL          1       /*ENABLE signal polarity*/
#  define R61581_ORI          0       /*0, 180*/
#  define R61581_LV_COLOR_DEPTH 16    /*Fix 16 bit*/
#endif

/*------------------------------
 *  ST7565 (Monochrome, low res.)
 *-----------------------------*/
#ifndef USE_ST7565
#  define USE_ST7565          0
#endif

#if USE_ST7565
/*No settings*/
#endif  /*USE_ST7565*/

/*------------------------------
 *  GC9A01 (color, low res.)
 *-----------------------------*/
#ifndef USE_GC9A01
#  define USE_GC9A01          0
#endif

#if USE_GC9A01
/*No settings*/
#endif  /*USE_GC9A01*/

/*------------------------------------------
 *  UC1610 (4 gray 160*[104|128])
 *  (EA DOGXL160 160x104 tested)
 *-----------------------------------------*/
#ifndef USE_UC1610
#  define USE_UC1610          0
#endif
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

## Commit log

2022-12-14 初始模板
2022-12-14 加入vscode
2022-12-21 优化代码，方便他人开发
2022-12-22 完成任务创建模板，gui显示方位调整
2022-12-28 增加smartconfig连接
2023-01-31 修改部分架构
2023-02-01 增加net任务
2023-02-02 WiFi连接测试，还需对断连场景做出处理
2023-02-04 修改分区表，WiFi连接成功，增加异常状态处理（需要确认是否考虑到所有情况）
    [partitions.csv]
2023-02-05 增加json解析接口，增加wifi连接完成信号量，增加sntp时间测试
2023-02-05 增加天气API输入（待优化整理）
2023-02-05 修复运行一段时间自动复位bug（未释放http资源）
2023-02-18 网络天气时间获取完成
2023-02-25 加载动画ui设计完成
2023-02-26 优化WiFi连接失败错误警告文本
2023-02-27 网络时间显示移植完成
2023-02-28 增加json第一次解析完成标志位，防止空指针
2023-03-04 增加rgb灯光效果渐变
2023-03-11 优化加载界面动画，优化初始时间界面显示，增加天气温度，待增加天气图片，等其他信息
2023-03-14 增加天气图片，ip定位地址
2023-03-16 基本升级完成，待测试
2023-03-18 更新刷新bug
2023-03-21 修复bug（太捞了！）
2023-03-28 更改sntp地址，防止连接不上
2023-03-30 优化一个bug，防止出现未知天气的问题
2023-04-15 取消毕设工程，将毕设所以资料移植至此仓库
    [3d概念图.3MF, ESP32_Albums.SchDoc, ESP32_project.PrjPcb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]
2023-04-17 V2.0.0新模型
    [底座.stl]
2023-04-17 删除重复文件
2023-06-12 优化 若出现连接失败复位后，时间无法显示bug
2024-08-18 增加强制门户认证连接WiFi方式
    [partitions.csv]
